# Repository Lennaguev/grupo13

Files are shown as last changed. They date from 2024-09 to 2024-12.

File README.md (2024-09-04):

# Fundamentos de biodiseño

| Integrantes: | Descripción: | Rol: |
| ----- | :---- | :---- |
| **ABIGAIL KARINA ALCAZAR VARGAS  ** |  Estudiante de 4to ciclo de ingeniería biomédica interesada en ingeniería de tejidos y en señales e imágenes biomédicas. |  **Diseño 3D** *Como encargada del diseño 3D, crearé modelos tridimensionales detallados y ajustaré el diseño protésico según las necesidades del usuario para asegurar que el producto sea funcional y cómodo*. |
| **PAOLO FABIÁN CARRANZA IZQUIERDO  ** |  Estudiante de Ingeniería Biomédica de 4to ciclo interesado en Ingeniería de tejidos y biomecánica. |  **Encargado de la manufactura digital:** *Como encargado de la manufactura digital desarrollaré estrategias para integrar diversas tecnologías en el diseño y fabricación del producto final. Además supervisaré la implementación de herramientas de impresión 3D y corte láser.*  |
|  **LADY PAOLA ECHEVERRÍA VÁSQUEZ** |  Estudiante de 4to ciclo de la carrera de ingeniería biomédica. Interesada en Ingeniería de biomateriales e ingeniería clínica. |  **Coordinadora y encargada del Git:** *Como coordinadora y responsable del Git, gestionaré el control de versiones y cambios en el repositorio. Coordinaré las actualizaciones del proyecto y ofreceré soporte al equipo en el uso de Git. También me aseguraré de que la documentación e información sea precisa y confiable.* |
| **LENNA ZURIEL GUEVARA GUILLEN  ** |  Estudiante de 4to ciclo de la carrera de ingeniería biomédica. Interesada en Ingeniería de tejidos y en Biomecánica. |  **Encargada de la elaboración del prototipado:** Como encargada de la *elaboración del prototipado, diseñaré y desarrollaré el prototipo utilizando diversas técnicas y herramientas. Además coordinaré el proceso desde la conceptualización hasta la fabricación, asegurando que los prototipos cumplan con los requisitos y estándares del usuario.*  |
| **VIVIANA NINOSKA RIVERA GUILLÉN  ** |  Estudiante de 4to ciclo de ingeniería biomédica interesada en ingeniería de tejidos y Biomecánica. |  **Encargada del diseño electrónico.** *Como encargada del diseño electrónico, desarrollaré esquemas y circuitos electrónicos para el proyecto, asegurando su funcionalidad y eficiencia. Asimismo, coordinaré y supervisaré la integración de los componentes y sistemas electrónicos al prototipo.* |

[image1]: <>

[image2]: <>

[image3]: <>

[image4]: <>

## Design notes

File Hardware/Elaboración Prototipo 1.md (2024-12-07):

# Elaboración de 1er Prototipo

1. **Diagrama de 4 Módulos HX711 (Diseño Esquemático)**
2. **Soldadura de Cableado a Galgas Extensiométricas:**
   * *Cableado Directo a Galgas*
   * *Soldadura de Terminales a Cables más gruesos y largos*
   * *Soldadura a Terminales Jumper para correcto enganche a Protoboard*
   * *Colocación de Termocompresores en puntos de soldadura*
3. **Inserto de las resistencias y los Terminales finales del cabledo de las galgas (2:2) para establecer 4 Puentes Wheatstone en el Protoboard**
4. **Soldadura de Pines a los módulos HX711**
5. **Encaje de Cables entre los Puentes y las ntradas de módulos HX711**
6. **Conexión de los módulos HX711 a un microcontrolador ESP32**
7. **Carga del código al ESP32 medinte el programa Arduino IDE (con sus respectivas extensiones)**
8. **Establecimiento de un sistema de carga para el ESP32**
    * *Soldadura de pines a un TP4056*
    * *Soldadura de cables con terminal Jumper a un interruptor*
    * *Conexión de caableado Batería Lipo -> TP4056 -> Interruptor -> ESP32*
9. **Lijado de Impresión 3D en PLA para acoplar los componentes electrónicos en sus respectivos espacios**
10. **Testeo de funcionamiento mediante deformaciones controladas de las galgas (sensores resistivos)**

*PDTA.: Mínimo Porcentaje de Éxito en 1er Cableado de Galgas*

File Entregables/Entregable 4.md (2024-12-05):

###     **1.- Caja Negra**


#### **Entradas:**

1. **Fuente de energía:** Mantiene activos los sensores, el sistema de procesamiento de señales, y la comunicación con dispositivos externos para el almacenamiento o transmisión de datos.  
2. **Presión en el muñón:** Datos obtenidos de los sensores  
3. **Forma y tamaño del muñón:** Influye directamente en la distribución de la presión y la forma en que el socket se ajusta al cuerpo del paciente.

#### **Salidas:**

1. **Datos sobre zonas de máxima presión:** Información precisa sobre las áreas específicas del muñón donde se ejerce la mayor presión, representada en forma de gráficos o valores numéricos.  
2. **Información sobre la distribución de fuerzas en situaciones dinámicas:** Datos que muestran cómo cambian las fuerzas en el muñón durante actividades como caminar, correr o subir escaleras.

### **2.- Esquema de Funciones**

* **Operar:** Operar los sensores alimentando enérgicamente los componentes del proyecto  
* **Captura:** Capturar los datos de la muestra (presión, tensión y cambio volumétrico) mediante los sensores  
* **Almacenar:** Almacenar los datos capturados para que pueda ser utilizado posteriormente por el médico  
* **Procesar:** Procesar los datos e información obtenida.  
* **Avisar:** Avisar cuando se excedan los rangos de presión y tensión preestablecidos.  
* **Transmitir:** Hacer pasar el cambio de datos almacenados a través del tiempo por el circuito hasta el punto de visualización.

### **3.- Matriz Morfológica**  


### **4.- Tabla de valoración**

|  |  | Conceptos de solución |  |  |
| :---- | :---- | :---- | :---- | :---- |
| **Número** | **criterios técnicos y económicos** | **Opción 1** | **Opción 2** | **Opcion 3** |
| **1** | **Facilidad de uso** | **4** | **1** | **2** |
| **2** | **Seguridad** | **4** | **3** | **3** |
| **3** | **Costo de tecnología** | **4** | **2** | **2** |
| **4** | **Precisión del dispositivo** | **3** | **3** | **4** |
| **5** | **Tamaño** | **4** | **4** | **4** |
| **6** | **Ligereza** | **4** | **3** | **2** |
| **7** | **Nivel de innovación** | **4** | **2** | **3** |
| **Suma total** |  | **27** | **18** | **20** |

### **5.- Conclusión:**

La opción 1 se destaca entre las tres propuestas debido a que obtuvo la mayor puntuación en la tabla de valoración, lo que refleja su superioridad en varios aspectos clave. Su diseño e implementación son intuitivos y amigables para los usuarios, lo que facilita su uso. Además, sobresale en términos de seguridad, haciéndola más confiable y reduciendo los riesgos potenciales para los usuarios. Otro aspecto importante es su alta calificación en cuanto a tamaño y ligereza, lo que la convierte en una opción altamente portátil y cómoda para el uso prolongado, lo cual es fundamental en aplicaciones donde la movilidad es crucial. Aunque la opción 1 no es la más precisa de todas las alternativas presentadas, los datos que proporciona son lo suficientemente confiables para cumplir con los requisitos del proyecto. 

### **6.- Bocetos:**

#### Boceto 1:
###### TÍTULO DE PROPUESTA: CALCETÍN SEMI-FLEXIBLE DE SILICONA PARA MONITOREO DE PUNTOS DE PRESIÓN NOTIFICADO DE MANERA INALÁMBRICA
Bocetos Propuesta 1 FUNBIO

#### Boceto 2:


LISTA DE DESPIECE:
| Pieza | Nombre | Material |
| :---- | :---- | :---- |
| 1 | 16/8 galgas extensiométricas |
| 2 | Batería |
| 3 | Interruptor |
| 4 | 1 Arduino Nano / ESP32 |
| 5 | Resistencias |
| 6 | Protoboard |
| 7 | Recubrimiento general | Silicona |
| 8 | Cajita para Microcontrolador Energizado | PLA |
| 9* | Módulo Bluetooth HC05 |
|10* | Pantalla LCD 4x20 |
|11* | Módulo I2C |
|12* | 4 Módulos HX711 |

(*) -> Por definir si será requerido al final (más parte B)

##### DESCRIPCIÓN DE FUNCIONAMIENTO:

Esta superficie se encarga de medir presión en determinados puntos principales en el muñón, colocando esta al interior del socket. La información que captan sus sensores es enviada vía Bluetooth a una pantalla, la cual puede ser un celular, con lo que se puede ver los puntos que presentan presiones superiores o inferiores a lo normal. El más peligroso será alertado con un mensaje de "Cuidado" o "!!!".



























































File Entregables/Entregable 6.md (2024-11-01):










https://cad.onshape.com/documents/64f8fe0cf73936eec21aee19/w/a115c0a505cd3cc3481bd7ef/e/b61a0160956c2c94d8190df8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

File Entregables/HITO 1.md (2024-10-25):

Captura de pantalla 2024-10-24 222601





















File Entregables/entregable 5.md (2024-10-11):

**1.- Esquema Electrónico de la solución planteada**  
****

**2.- Modelado 3D**  


![][![image](https://github.com/user-attachments/assets/08fa5246-66a7-4291-986a-df6649042290)


[https://skfb.ly/prHDR](https://skfb.ly/prHDR) 



[https://skfb.ly/prHEy](https://skfb.ly/prHEy) 



[https://skfb.ly/prHEH](https://skfb.ly/prHEH) 



[https://skfb.ly/prHEL](https://skfb.ly/prHEL)



[https://skfb.ly/prHEO](https://skfb.ly/prHEO)  



[https://skfb.ly/prHF8](https://skfb.ly/prHF8)  



[https://skfb.ly/prHF9](https://skfb.ly/prHF9)



[https://skfb.ly/prHFx](https://skfb.ly/prHFx)  



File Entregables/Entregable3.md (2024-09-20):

**Problemática**

- **Contexto:**  
  El proceso de amputación de miembros inferiores es un procedimiento quirúrgico irreversible que se lleva a cabo por causas traumáticas (accidentes o lesiones) o no traumáticas (enfermedades como la diabetes o problemas vasculares) \[1\]. A nivel global, las amputaciones de miembros inferiores representan el 65% del total de personas amputadas, de las cuales el 44.6% son de nivel A.K. (por encima de la rodilla) \[2\]. Asimismo se sabe que en países desarrollados, la principal causa de estas amputaciones son las complicaciones asociadas a enfermedades preexistentes, mientras que en países en vía de desarrollo, los accidentes y traumas son los principales factores \[3\]. En el ámbito de la ingeniería biomédica, esta situación adquiere gran relevancia debido a la necesidad de desarrollar soluciones que ayuden a los pacientes a enfrentar desafíos físicos, psicológicos y sociales y a recuperar su movilidad y calidad de vida. Las prótesis avanzadas, el tratamiento postoperatorio, y la rehabilitación integral son áreas clave en las que la ingeniería biomédica desempeña un papel fundamental para mitigar los efectos de la amputación y facilitar la reintegración de los pacientes a su vida cotidiana.  
- **Definición del problema:**  
  El problema específico que se aborda es la ***falta de una adecuada adaptabilidad de las prótesis al muñón en pacientes con amputación a nivel AK F3,*** lo que dificulta la marcha y reduce la eficacia del proceso de rehabilitación. Este problema surge debido a varios factores, como la forma irregular del muñón, la presión inadecuada en áreas sensibles, y el uso de materiales o tecnologías que no permiten un ajuste preciso. La consecuencia directa es una marcha inestable y dolorosa, que limita la movilidad y la independencia del paciente, afectando su bienestar físico y emocional.   
- **Impacto:**   
  El impacto de la falta de adaptabilidad adecuada de las prótesis no solo afecta la movilidad y calidad de vida de los pacientes, sino que también genera mayores costos médicos para el sistema de salud. Una prótesis mal adaptada puede ocasionar diversas complicaciones físicas, tales como **heridas en el muñón,**  **neuromas** y **necrosis** \[2,4\], las cuales suelen requerir tratamientos adicionales, hospitalizaciones prolongadas y, en algunos casos, revisiones quirúrgicas o cambios de prótesis. Estos problemas incrementan la necesidad de atención médica continua, lo que genera una presión significativa sobre los recursos y los costos del sistema de salud. Además, los pacientes con prótesis mal ajustadas pueden sufrir dolor crónico, mayor riesgo de infecciones, y dificultades para realizar actividades cotidianas, lo que afecta gravemente su calidad de vida y su capacidad para lograr una rehabilitación exitosa. A nivel económico, los costos adicionales derivados de los procedimientos médicos repetidos y la necesidad de prótesis nuevas o reajustadas representan un desafío para los sistemas de salud, que deben invertir más recursos en la atención de estos pacientes. Estos costos se ven reflejados en un uso ineficiente de los servicios de rehabilitación y un aumento en las tasas de reingreso hospitalario. Por lo tanto, el desarrollo de prótesis mejor adaptadas y personalizadas no solo mejoraría la calidad de vida de los pacientes, sino que también reduciría los costos asociados a complicaciones postoperatorias y el uso prolongado de los servicios médicos, beneficiando tanto a los pacientes como a los sistemas de salud en general.

**Propuesta de solución:** 

- **Descripción de la solución:**   
- Se plantea el desarrollo de un revestimiento de silicona semi-flexible, en el cual se integrarán galgas extensiométricas con la capacidad de medir de manera precisa los puntos de mayor presión, compresión y tensión ejercidos sobre el muñón. Este revestimiento se colocará antes del encaje protésico, permitiendo obtener un mapa detallado de las fuerzas que actúan sobre las distintas áreas del muñón durante su interacción con el socket.  
- El objetivo principal de esta tecnología es facilitar la identificación de las zonas que requieren ajustes en el diseño del socket, permitiendo reducir significativamente el tiempo de personalización del mismo. Al obtener información precisa y en tiempo real sobre las zonas de alta presión o tensión, será posible adaptar el socket de manera más rápida y efectiva, mejorando la comodidad y reduciendo las posibilidades de lesiones o irritación para el paciente. De esta forma, se optimiza el proceso de diseño del encaje protésico, garantizando que se satisfagan las necesidades individuales del usuario.

- **Características:**  
- Mide la presión ejercida sobre el muñón mientras el usuario realiza sus actividades diarias, lo que permitirá identificar las posiciones y movimientos que generan más variación de presión.  
- A través de los datos recopilados, se podrán identificar las zonas que están sometidas a una presión excesiva, ayudando así a que la personalización del encaje sea precisa.  
    
- **Beneficios:**   
- Al ser solo un revestimiento no está limitado a un tipo de socket en específico, sino que puede ser usado debajo de cualquiera de estos.  
- Además de mejorar la elección del socket adecuado para el usuario en la etapa inicial, en etapas posteriores se puede utilizar para identificar variaciones en el volumen del muñón y así realizar los ajustes necesarios en el socket del usuario.  
    
- **Viabilidad Técnica:**   
    
  **Materiales:**  
- **Silicona:** El material del revestimiento debe ser cómodo, biocompatible y duradero. La silicona es ideal por su elasticidad, capacidad de adaptación al muñón y resistencia al desgaste. Además, debe ser lo suficientemente fina para no interferir con la precisión de los sensores.  
- **Galgas extensiométricas**: Son sensores de alta precisión que detectan cambios en la tensión mecánica del material. Las galgas deben ser miniaturizadas y lo suficientemente sensibles para captar los pequeños cambios que ocurran en las distintas zonas del muñón.  
  **Componentes electrónicos:**  
- **Microcontroladores**: Dispositivos como Arduino o Raspberry Pi para procesar las señales provenientes de las galgas extensiométricas y convertirlas en datos de utilidad.    
- **Baterías o fuentes de energía autónomas**: baterías pequeñas, recargables y de larga duración para no interferir con la comodidad del usuario.  
  **Software de análisis:**  
- **Programa de procesamiento de datos**: El desarrollo de un software especializado es crucial para analizar los datos obtenidos por las galgas. Este software debe generar mapas de presión y tensión

  **Conocimientos necesarios:**

- ### Diseño e integración de galgas extensiométricas en materiales como la silicona, así como la creación de circuitos y sistemas electrónicos capaces de manejar múltiples entradas de sensores. Se controlará el flujo de cargas mediante resistores agrupados según lo que necesite cada parte de circuito.

- Conocimiento de la biomecánica del muñón, para saber dónde colocar los sensores y cómo interpretar las deformaciones detectadas. Es importante comprender cómo el muñón interactúa con el socket y cómo varían las fuerzas en diferentes actividades.  
- Programación y diseño de interfaces para desarrollar el software que procesará los datos. Este punto se desarrollará teniendo en cuenta los conocimientos previos adquiridos en la carrera, como en el curso de Fundamentos de Programación y Diseño Industrial.

  **Coherencia**

- **Contexto del Proyecto:**  
  La propuesta solución elegida en este caso es el revestimiento de silicona con galgas extensiométricas que midan los puntos de presión, compresión y tensión en el muñón. Consideramos que esta propuesta es necesaria en este caso debido a que el principal problema que identificamos entre amputados que logramos entrevistar; Fue que comúnmente cuando se les daba la primera prótesis era muy común que esta no les quedará del todo bien por aumento de peso, diferente ajuste, entre otras. Lo cual conllevaba a un rediseño del socket.  
  Lo que busca nuestra solución es hacer el proceso de la prueba del socket menos tedioso y  más cómodo para el paciente; Ya que este revestimiento formado por galgas extensiométricas que iría antes de poner el socket mediría como se deforma el muñón en el tiempo, en la primera etapa de creación del socket, dando estos resultados al médico para que pueda reducir el tiempo de prueba del socket con los resultados obtenidos.  
  La manera en la que se integra al entorno general de ingeniería biomédica es porque se usarán biomateriales como la silicona el cual es un polímero que se usa en distintos instrumentos biomédicos gracias a su característica elasticidad. Por otro lado, para medir las presiones y tensiones se utilizaran biosensores y las galgas también medirán el volumen de todo el muñón. El campo de ingeniería biomédica genera este tipo de soluciones que mejoran el proceso ya existente en este caso de prueba de socket con una herramienta biomédica hecha a partir de biomateriales que simplifique y agilice este proceso.  
    
- **Objetivos del Proyecto:**   
  El *objetivo general* de la propuesta de solución es simplificar el proceso de prueba del socket para que se realicen las menores pruebas posibles y el paciente pueda usar su socket y que este se ajuste bien.  
  Mientras que los *objetivos específicos* son que mientras este revestimiento conformado por galgas mida el tamaño del muñón también pueda dar datos de donde se produce los puntos de presiones y tensiones del muñón. Para que así se identifique donde deberían producirse y donde no. De esta forma estos datos también serán de conocimiento del médico que lo tendrá en consideración durante el desarrollo del socket y para la prevención de posibles heridas por exceso de presión en puntos sensibles.  
     
- **Justificación del Prototipo:**   
  Consideramos que nuestra propuesta de solución es innovadora frente a otras del mercado debido a que este es un revestimiento hecho de silicona que es un material que, además de cómodo, su principal función es que evita el contacto directo del muñón con el socket. A pesar de que ya existen revestimientos para que el muñón no tenga contacto directo con el socket, la gran diferencia radica en que nuestra solución contiene galgas que miden los puntos de presión claves dentro del muñón a lo largo del tiempo para conocer cómo se presenta su sensibilidad. Además, estos sensores de presión distribuidos en el revestimiento ayuda para notificar al médico si se está haciendo presión en algún lugar específico sensible que podría generarle heridas al pacientes, lo que prevendría lo que, en casos normales, implicaría la suspensión del uso de la prótesis temporalmente.  
    
- **Alineación con el Problema:**   
  La problemática específica es la falta de adaptabilidad de la prótesis al muñón y cómo esto puede generar complicaciones. Parte de estas complicaciones son heridas que se pueden ocasionar en el muñón, las cuales generarán costos adicionales al paciente para tratar este problema, y no solo al paciente, sino también al sistema de salud. El prototipo aborda eficazmente la problemática, ya que se caracteriza por medir con precisión la presión que genera el el muñón sobre el socket y en qué zonas se dan presiones excesivas que pueden causar complicaciones. Con los datos proporcionados de las mediciones, se podrán realizar ajustes personalizados rápidamente lo  que facilitará la adaptabilidad de la prótesis al muñón.  

- **Resumen:**  
  El problema identificado radica en la falta de adaptabilidad de las prótesis al muñón en pacientes con amputación por encima de la rodilla (nivel AK F3), lo que afecta negativamente su movilidad y proceso de rehabilitación. La forma irregular del muñón y la distribución desigual de presión y tensión en las áreas sensibles del muñón contribuyen a una marcha inestable y dolorosa, limitando la independencia del paciente.   
  La solución propuesta es desarrollar un revestimiento de un biomaterial semi-flexible que contenga galgas extensiométricas. Estas galgas medirán la presión, tensión y cambio volumétrico del muñón de forma instantánea, lo cual nos proporcionará información precisa y detallada de las diversas presiones que actúan en distintas partes específicas del muñón durante el uso de la prótesis. Esto permitirá ajustar de manera minuciosa y rápida el socket protésico, mejorando la comodidad y reduciendo las posibilidades de lesiones o irritación en el paciente.  
- **Resultados esperados:**   
  Al desarrollar esta solución, se espera obtener:  
- Un proceso más eficiente y preciso de personalización del socket protésico el cual  optimizará el tiempo de rehabilitación de los pacientes.  
- Una reducción en el número de pruebas de ajuste de socket, lo que resultaría en menos incomodidad para el paciente.  
- Mejora en la calidad de vida del paciente, al evitar complicaciones como heridas o necrosis debido a una mala adaptación.  
  Para testear conceptualmente el prototipo, se podría realizar una simulación en la que se evalúe cómo el revestimiento con galgas responde a diferentes niveles de presión y tensión. Estos resultados se utilizarían para ajustar el diseño del socket con la finalidad de que se reduzca significativamente el tiempo de personalización antes de su fabricación final.  
- **Siguientes pasos**  
- Desarrollar un prototipo inicial del revestimiento con los materiales y componentes electrónicos propuestos.  
- Realizar pruebas en condiciones controladas para validar la precisión de las galgas extensiométricas en la medición de la presión y tensión.  
- Reformular el diseño y realizar ajustes basados en los resultados de las pruebas.  
- Desarrollar el software necesario para procesar los datos obtenidos y generar estadísticas de datos útiles para los médicos.

**Referencias Bibliográficas:**  
\[1\]  UC San Diego Health, "Cardiovascular Tests and Procedures," MyHealth, \[En línea\]. Disponible en: [https://myhealth.ucsd.edu/Spanish/TestsProcedures/Cardiovascular/92,P09333](https://myhealth.ucsd.edu/Spanish/TestsProcedures/Cardiovascular/92,P09333).  \[Accedido: 27-Ago-2024\].   
\[2\] Amputee Coalition, "Above Knee Amputation," Amputee Coalition, Aug. 2024\. \[En línea\]. Disponible en: [https://www.amputee-coalition.org/wp-content/uploads/2024/08/Above-Knee-Amputation-English.pdf](https://www.amputee-coalition.org/wp-content/uploads/2024/08/Above-Knee-Amputation-English.pdf).  \[Accedido: 27-Ago-2024\].   
\[3\] T. Kaylor, "INCIDENCE AND COMMON CAUSES OF MAJOR LOWER LIMB AMPUTATION AT A HOSPITAL IN A SUB-DISTRICT OF THE CITY OF CAPE TOWN MUNICIPALITY." Master's thesis, University of the Western Cape, 2024\. \[En línea\]. Disponible en: [https://etd.uwc.ac.za/xmlui/bitstream/handle/11394/10643/kaylor\_chs\_m\_2024.pdf?sequence=1\&isAllowed=y](https://etd.uwc.ac.za/xmlui/bitstream/handle/11394/10643/kaylor_chs_m_2024.pdf?sequence=1&isAllowed=y).  \[Accedido: 27-Ago-2024\].   
\[4\] M. Rodríguez, "Características clínicas y epidemiológicas de los pacientes amputados en el Hospital General de Ciego de Ávila," Revista Médica de Ciencias de la Salud, vol. 8, no. 2, pp. 123-130, 2023\. \[En línea\]. Disponible en: [https://revmediciego.sld.cu/index.php/mediciego/article/view/632/1171](https://revmediciego.sld.cu/index.php/mediciego/article/view/632/1171).  \[Accedido: 27-Aug-2024\].

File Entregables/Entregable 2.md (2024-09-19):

1. **Contexto comercial:**
   
   *1.1 Equipos o dispositivos existentes:*

|  Equipos  |  Resumen  |  Imagen  |
| :---- | :---- | :---- |
|  Rodilla de tipo policéntrico [\[1\]](https://dspace.ups.edu.ec/bitstream/123456789/19995/1/UPS-CT008995.pdf)  |  Está destinada para la adaptación protésica de los pacientes. Hay distintos modelos de rodillas policéntricas pero el sistema en el que se basa su funcionamiento es el de distintos puntos de pivote que permiten un movimiento oscilatorio de la rodilla, mejorando así la marcha del paciente. La innovación que se le hace a estos equipos es el material con el que se fabrican siendo que por tecnologías aditivas el coste y el material utilizado presentan un costo y tiempo de fabricación más bajos del mercado. [\[1\]](https://dspace.ups.edu.ec/bitstream/123456789/19995/1/UPS-CT008995.pdf)  |    |
|  Revestimiento de sellado Skeo [\[2\]](https://www.ottobock.com/de-de/product/6Y110)  |  Este revestimiento está compuesto de silicona, que ofrece una mejor comodidad en el usuario, es sencillo de colocar, además, según la experiencia del usuario, se siente seguro a no perder la prótesis y al no tener una tela exterior no almacena agua. [\[2\]](https://www.ottobock.com/de-de/product/6Y110) Especificaciones del producto: Grado de movilidad (2,3,4); Peso corporal máximo: sin límite; para Nivel de amputación transfemoral.  |    |
|  Almohadillas de presión [\[3\]](https://www.ossur.com/es-mx/protesica/encajes/pressure-pads)  |  Tienen el objetivo de redistribuir los puntos de presión que hay en el muñón que se dan en zonas ósea prominentes. El material es de silicona no comprensible y que pueden mejorar la comodidad de los encajes laminados, termoformados o fabricados directamente. [\[3\]](https://www.ossur.com/es-mx/protesica/encajes/pressure-pads) Especificaciones del producto: Niveles de impacto (Bajo, moderado, alto y extremo); para Nivel de amputación Transfemoral y Transtibial. |    |

   *1.2 Patentes*
|  Patente de invención  |  Ficha Técnica  |  Resumen  |  Imagen  |
| :---- | :---- | :---- | :---- |
|  Electrodo Flexible para detectar cambios en la Temperatura, Humedad y Concentración de iones de Sodio en el sudor [\[4\]](https://patentscope.wipo.int/search/en/detail.jsf?docId=US90328810)  | ***N° de patente:*** US20130197319. ***Procedencia:*** Estados Unidos. ***Inventores:*** Chelsea N Monty; Evan K Wujcik; Nathaniel Jacob Blasdel.  |  La invención describe una plataforma flexible de sensores amperométricos para aplicaciones biomédicas, diseñada para monitorear parámetros fisiológicos como temperatura, humedad y concentración de iones, en fluidos corporales mediante detección y diagnóstico de posibles afecciones médicas como irritación o infecciones. Se menciona su uso en el diagnóstico de fibrosis quística y la monitorización de prótesis en amputados. El sensor incluye capas de nanocompuestos y materiales conductivos como nanotubos de carbono y conductores MWCNT y PPy. Proporciona detección en tiempo real y se destaca por su flexibilidad, lo que mejora el confort y la precisión en su aplicación sobre la piel. [\[4\]](https://patentscope.wipo.int/search/en/detail.jsf?docId=US90328810)  |    |
|  Socket integrado para Prótesis que contiene sensor de resistencia [\[5\]](https://worldwide.espacenet.com/patent/search/family/082401693/publication/KR102416665B1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)  |  ***N° de patente:*** KR102416665B1. ***Procedencia:*** Corea. ***Inventores:*** KIM JOO HYUNG; LEE SUN KON; KWON HYEON JUNG; SHIN KYEONG HO; KIM JOO HYUNG; LEE SUN KON; KWON HYEON JUNG; SHIN KYEONG HO.  |  Esta patente de socket está diseñada con el objetivo de ser más cómodo para el amputado mediante material blando elástico, que está integrado dentro del socket, así no provocará dolores en la persona cuando varíe su volumen como es el caso de un aumento del peso corporal, además consta de un sensor de resistencia que mide el cambio de volumen y que posteriormente de los datos obtenidos se podrán utilizar para tratamientos y rehabilitación del usuario.[\[5\]](https://worldwide.espacenet.com/patent/search/family/082401693/publication/KR102416665B1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)  |    |
|  Dispositivo para monitorear la presión/temperatura para Prótesis [\[6\]](https://worldwide.espacenet.com/patent/search?q=pn%3DMXPA05004653A)  |  ***N° de patente:*** MXPA05004653A. ***Procedencia:*** México. ***Inventores:*** CASPERS CARL A.  |  Este dispositivo consiste en un conjunto de sensores (presión, fuerza, temperatura, humedad y vacío) que permiten detectar nivel fuera de la saludable en la unión entre el miembro residual y el receptáculo como una descolocación por un insuficiencia en la bomba de vacío; por inflamación o pérdida de irrigación sanguínea; o por demasiado humedad debido a sudor. [\[6\]](https://worldwide.espacenet.com/patent/search?q=pn%3DMXPA05004653A)  |    |
|  Sistema de presión de aire diferencial [\[7\]](https://patentimages.storage.googleapis.com/15/db/f9/e8f75be83b4f33/ES2763123T3.pdf)  |  ***N° de patente:*** ES2763123T3. ***Procedencia:*** España. ***Inventores:*** LONG, PHILIP, W.; KUEHNE, ERIC, R.; RAHMAN, BABU, S.; JUE, CLIFFORD, T.; WHALEN, SEAN, TREMAINE; MARECEK, GREGORY, P.; HORST, ROBERT, W.; ABRAHAMI, ADRIAN; CURTISS, CHASE, CAMDEN y ESSOCK-BURNS, EMMA.  |  Un sistema de presión de aire diferencial que tiene capacidades de corrección de la marcha se integra con una prótesis En este ejemplo específico, la integración de un sistema de presión de aire diferencial con capacidades de marcha como se ha descrito anteriormente con capacidades de control por máquina, permite la información o el entrenamiento usando movimiento de memoria muscular. Los sistemas de presión de aire diferencial se puede configurar para dirigir al usuario a opciones de socket y a mejorar su marcha. [\[7\]](https://patentimages.storage.googleapis.com/15/db/f9/e8f75be83b4f33/ES2763123T3.pdf)  |    |

2. **Requerimientos**

    Requisitos Funcionales FUNBIO   Requisitos No Funcionales FUNBIO

4. **Propuesta de Solución**  
   ### “Socket con sensor de presiones que pueda detectar puntos de mayor apoyo, esto para que el paciente pueda mejorar su locomoción y evitar posibles lesiones e incomodidad en el muñón a través de la colocación adecuada de la prótesis o su correcta elaboración de parte de la institución médica en un inicio.”

**7.- Referencias bibliográficas:**

- \[1\] F. V. Pintado Albarracin, G. F. Vintimilla Leon, “Diseño y construcción de una prótesis de rodilla asistida para amputación transfemoral” Sep. 2020. https://dspace.ups.edu.ec/bitstream/123456789/19995/1/UPS-CT008995.pdf 
- \[2\] Ossur “Skeo Sealing Liner” 2024 https://www.ottobock.com/de-de/product/6Y110   
- \[3\] Ossur “Pressure pads” 2024 https://www.ossur.com/es-mx/protesica/encajes/pressure-pads    
- \[4\] Chelsea N Monty, Evan K Wujcik, Nathaniel Jacob Blasdel, “WIPO - Search International and National Patent Collections.” Aug. 01, 2013. https://patentscope.wipo.int/search/en/detail.jsf?docId=US90328810 
- \[5\] KIM JOO HYUNG; LEE SUN KON; et al., “Integrated Socket For Prosthesis Including Resistance Sensor.” Julio, 05, 2022. https://worldwide.espacenet.com/patent/search/family/082401693/publication/KR102416665B1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 
- \[6\] Caspers Carl A, “Pressure/Temperature Monitoring Device For Prosthetics” Septiembre, 20, 2005. https://worldwide.espacenet.com/patent/search?q=pn%3DMXPA05004653A
- \[7\] Long, Philip, W.; Kuehne, Eric, R.; et al., “Cámara de presión y elevador para sistema de presión de aire diferencial con capacidad de recogida de datos médicos” Nov. 06, 2019. https://patentimages.storage.googleapis.com/15/db/f9/e8f75be83b4f33/ES2763123T3.pdf

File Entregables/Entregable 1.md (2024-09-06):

1. **Definiciones de términos clave:**  
* ***Amputación de miembro inferior derecho AK F3:*** Esta amputación implica extirpar la parte superior de la rodilla a la altura del tercio inferior del fémur.  
* ***Diabetes Mellitus :*** Enfermedad crónica que implica niveles altos de glucosa en la sangre.
* ***Accidente automovilístico:*** Consecuencia de una colisión de coche  
* ***Terapia Preprotésica:*** Se prepara a la persona para el manejo de la prótesis provisional o pilón.
* ***Fase Protésica:*** Se aprende a colocarse y retirarse la prótesis, así como la continuación de la rehabilitación tanto física como funcional.
    
2. **Análisis de la temática y/o caso:**  
   *2.1 Contexto mundial:* 

La amputación de miembro inferior es un procedimiento quirúrgico irreversible que consta de la extirpación total o parcial de una extremidad del cuadrante inferior. Estas pueden ser causadas como consecuencia de un accidente o lesión *(Amputación traumática)* o enfermedad *(Amputación no traumática)*.[\[1\]](https://myhealth.ucsd.edu/Spanish/TestsProcedures/Cardiovascular/92,P09333) 
Los niveles de amputación existentes se clasifican de dos formas \[2\]:  
**a.- Clasificación anatómica de Oxford:** 

###### TABLA I: CLASIFICACIÓN ANATÓMICA SEGÚN OXFORD
| MIEMBROS INFERIORES |
| :---: |
| F: Segmento femoral
F1: Tercio superior del fémur
F2: Tercio medio del fémur
F3: Tercio inferior del fémur
T: Segmento tibial
T1: Tercio superior de tibia
T2: Tercio medio de tibia
T3: Tercio inferior de tibia |

**b.- Clasificación topográfica de Schwartz:**

###### TABLA II: CLASIFICACIÓN SEGÚN SCHWARTZ
| MIEMBROS INFERIORES |
| :---: |
| Hemipelvectomía
Desarticulación de cadera
Amputación por encima de la rodilla (A.K.)
Desarticulación de rodilla
Amputación corta bajo rodilla (short B.K.)
Amputación por debajo de la rodilla (B.K.)
Amputación de Syme
Amputaciones parciales del pie|

A nivel internacional, la amputación de miembros inferiores es la más común ya que constituye un 65% del porcentaje total de personas amputadas [\[3\]](https://www.amputee-coalition.org/wp-content/uploads/2024/08/Above-Knee-Amputation-English.pdf). De esta cifra, el 44,6% está compuesta de pacientes que han sido amputadas a nivel por arriba de la rodilla (A.K.). En los países desarrollados la mayor causa de amputaciones son complicaciones de enfermedades preexistentes *(Amputación no traumática)* siendo la diabetes y enfermedades vasculares las mayores originantes, por otro lado, en países subdesarrollados la mayor causa de amputaciones son accidentes o lesiones *(Amputación traumática)* [\[4\]](https://etd.uwc.ac.za/xmlui/bitstream/handle/11394/10643/kaylor_chs_m_2024.pdf?sequence=1&isAllowed=y).  
Una amputación trae consigo consecuencias físicas, funcionales, psicológicas y sociales, es por esto que el tratamiento posterior al procedimiento debe componerse de varias etapas guiadas con la ayuda de distintos especialistas, tales como médicos, fisioterapeutas y psicólogos. El tratamiento post-operatorio consta de 3 etapas [\[5\]](https://www.argentina.gob.ar/inareps/guia-atencion-pacientes-amputados/etapas):

- **Etapa post-quirúrgica:** En esta etapa es primordial la curación de la herida causada por el tratamiento quirúrgico, también se trata de disminuir los dolores y edemas que el paciente pueda sufrir por el mismo. Usualmente se usan vendajes, calcetas, yeso y pomadas. Esta etapa finaliza con la extirpación de los puntos y la cicatrización de la herida. Asimismo en esta etapa se pueden presentar diversas complicaciones con el muñón de las cuales las más frecuentes son las son infecciones en la herida con una presencia del 31.07% en los pacientes, los neuromas con una presencia del 19,64% y la necrosis con una presencia del 32,14%. Por otro lado,  otra de las complicaciones más frecuentes es el famoso síndrome de miembro fantasma el cual tiene una presencia del 80% y es mayormente causado por factores sociales a los que el paciente se encuentra sometido [\[6\]](https://revmediciego.sld.cu/index.php/mediciego/article/view/632/1171) [\[3\]](https://www.amputee-coalition.org/wp-content/uploads/2024/08/Above-Knee-Amputation-English.pdf).  
- **Etapa pre-protésica:** Se desarrolla de 2-3 semanas después de la cirugía y se basa principalmente en la adaptación del paciente a la vida diaria. Asimismo se empieza la confección del “Pilón”, el cual es un molde de yeso el cual es usado para el desarrollo muscular del muñón. Por otro lado, en esta etapa también se empieza a entrenar al paciente para el uso de la prótesis, esto mediante ejercicios de rehabilitación como por ejemplo; Ejercicios de equilibrio, aprender a ponerse la prótesis y prácticas de marcha en distintos terrenos [\[5\]](https://www.argentina.gob.ar/inareps/guia-atencion-pacientes-amputados/etapas).
- **Etapa protésica:** En esta etapa se desarrolla la prescripción de la prótesis considerando las necesidades del paciente. A su misma vez el paciente empieza el proceso de rehabilitación con el uso de la prótesis prescrita mediante técnicas especializadas como el entrenamiento A.V.D [\[5\]](https://www.argentina.gob.ar/inareps/guia-atencion-pacientes-amputados/etapas).

En suma, el objetivo principal del tratamiento al paciente amputado es que este aprenda a usar la prótesis prescrita por su médico, con la finalidad de que este pueda tener una óptima calidad de vida y reemplazar el miembro faltante  El éxito del tratamiento dependerá de distintos factores relacionados tanto al paciente (edad, el estado físico, la motivación que tenga para con su recuperación y el sistema de apoyo que tenga) como al personal de salud y las terapias usadas para su tratamiento [\[7\]](https://www.medigraphic.com/pdfs/revcubmedfisreah/cfr-2016/cfr161d.pdf).

*2.2 Contexto en el Perú:*  
Desde el 2017 al 2022 la región que registró un mayor número de accidentes de tránsitos fue Lima, donde se pudo ver un aproximado de 52% de casos. Durante el 2019 se pudo visualizar una alza de accidentes, presentando así una cantidad de 95 800 a diferencia del del 2020 donde se visualizó un descenso de accidentes debido al contexto histórico por el cual estaba pasando el mundo, donde la cantidad de accidentes presentados fue de 57 396\. Luego del descenso histórico de accidentes automovilísticos que se pudo ver en el año 2020, en el año 2021 se pudo ver una nueva alza de accidentes donde se presentó 74 624 accidentes, de los cuales hubo 49 519 heridos y 3 032 fallecidos.[\[8\]](https://www.defensoria.gob.pe/wp-content/uploads/2023/04/Reporte-Defensorial-de-accidentes-de-tr%C3%A1nsito-N01-Abril-2023.pdf)

###### TABLA III: ACCIDENTES DE TRÁNSITO, HERIDOS Y FALLECIDOS POR SINIESTROS VIALES EN EL PERÚ (2017 – 2022)


Las amputaciones traumáticas del miembro inferior que se dan por accidentes de tránsito  suelen ser a nivel por encima de la rodilla (A.K), en el Perú las amputaciones de este tipo son una de las más frecuentes con una incidencia del 54%; sin embargo, la amputación no traumática es la que se da con mayor frecuencia con una recurrencia del 55% y la causa en su mayoría es la complicación de la diabetes mellitus (42%).[\[9\]](https://www.essalud.gob.pe/ietsi/pdfs/guias/RE_Prescripcion_de_Protesis_Final.pdf)
Aunque un paciente haya sufrido una amputación traumática, el que éste padezca de diabetes será un problema para su tratamiento post-quirúrgico ya que esta enfermedad afecta a la cicatrización debido a que los altos niveles de glucosa en la sangre afectan el flujo sanguíneo ralentizando así el proceso de cicatrización. Lo mencionado influye en la etapa post-quirúrgica del tratamiento del paciente debido a las complicaciones que pueden ocasionarse lo que de la misma forma puede impedir la recuperación de la persona que a su misma vez puede afectar las siguientes etapas de recuperación.
En nuestro país los pacientes amputados solo cuentan con un centro especializado en  rehabilitación integral llamado Instituto Nacional de Rehabilitación (INR), el cual está ubicado en la capital.  En el año 2023 se diagnosticó y trató a  101 personas amputadas de nivel A.K en el Departamento de Amputados, Quemados y Trastornos Posturales (AQTP), los cuales representan el 4.3% de un total de 2347 personas.[\[10\]](https://cdn.www.gob.pe/uploads/document/file/5729586/5088554-rd-009-2024-sa-dg-inr.pdf)



Fig. 1: Indicadores hospitalarios anuales 2023

3. **Cuadro médico**  
   ###### TABLA IV: DESCRIPCIÓN DE CASO REAL CONSIDERADO POR EL GRUPO (INR)

| Prevención  | Diagnóstico  | Tratamiento  | Monitoreo |
| :---- | :---- | :---- | :---- |
| Para caso de antecedente de Diabetes mellitus: Ante posible úlcera isquémica con infección, la gangrena digital y la necrosis tisular (motivos para amputación mayor)[\[12\]](http://scielo.sld.cu/scielo.php?pid=S1682-00372020000300005&script=sci_arttext&tlng=pt), se recomienda tratamiento preventivo [\[13\]](https://scielo.isciii.es/scielo.php?pid=S2529-850X2022000200005&script=sci_arttext):| Amputación de miembro inferior derecho por accidente automovilístico | Radiografía del muñón, exámenes de laboratorio control (hemograma, hemoglobina glicosilada, perfil lipídico.| El 5 de enero del 2022 se procede con la realización de baremo para elaboración de certificado de discapacidad. 
|**\- Cuidado del pie con educación a pacientes:** \* Calzado adecuado \* Higiene adecuada \* Cuidado de heridas y corte de uñas \* Ejercicio físico: Disminuir la presión máxima y aumentar el rango de movimiento del pie y tobillo. **\- Evaluaciones periódicas de riesgos (signos):** \* Revisión de historial clínico: Presencia de enfermedad renal en etapa terminal y de limitaciones físicas \* Análisis del pie en color, temperatura y deformidades \* Presencia de lesiones como hallux valgus, atrofia muscular, deformidad de Charcot, eritema, ampollas, callosidades, fisuras, tinea pedis y uñas encarnadas. \* Pérdida de pulso pedio dorsal o sensación protectora. \* Control glucémico **\- Atención adecuada a úlceras/heridas:** \* Descarga \* Uso de yeso de contacto total \* Técnicas quirúrgicas: Tenotomía del tendón flexor digital, Alargamiento del tendón de Aquiles, tenosuspensión de Jones \* Desbridamiento (infección) \* Revascularización \* Terapia de heridas con presión negativa| | Se prescribe terapia física, ocupacional. Psicología y servicio social. | Luego de 2 meses, le indican uso de prótesis AK modular, socket de resina, con cinturón silesiano, rodilla monocéntrica, y pie SACH. En noviembre, inicia el entrenamiento de marcha al practicar con pilón de yeso, siendo previo a la prótesis definitiva. En ese momento se encontraba en espera de cobertura de seguro para su prótesis. Un año después, acude a control y su prótesis pasa a ser elaborada en biomecánica. Se indica terapia física y ocupacional para alineamiento protésico. Finalmente, 3 meses después se realiza el alta de la prótesis AK modular, socket resina, cinturón silesiano, rodilla con freno de fricción y pie SACH. Se prescribe un bastón canadiense.|

4. **Diagrama de Ishikawa**

   ![image](

   Fig. 2: Diagrama de Ishikawa con Causas relacionado a la problemática de Amputados

6. **Definición del problema**
   
   *“Dificultad en la marcha debido a problemas de adaptabilidad de la prótesis al muñón del paciente amputacion nivel AK F3”*   
     
8. **Estado del arte/ contexto científico**  

   ###### TABLA V: PRODUCTOS EN EL MERCADO PARA AMPUTADOS DEL MIEMBRO INFERIOR

| | |
| :---- | ----- |
| PIE SACH | Prótesis sin articulaciones en forma de pie, diseñada para brindar soporte .[\[13\]](https://revistas.uis.edu.co/index.php/revistauisingenierias/article/view/14789) |
| **ORION3** | Prótesis transfemoral que permite a los usuarios replicar el movimiento natural de sus extremidades [\[13\]](https://revistas.uis.edu.co/index.php/revistauisingenierias/article/view/14789) |
| **PLIE** | Prótesis con microprocesador, capaz de soportar hasta 125 Kg.[\[13\]](https://revistas.uis.edu.co/index.php/revistauisingenierias/article/view/14789) |
| **GENIUM** | Prótesis basada en microprocesador cuya batería dura más de 2 días. [\[13\]](https://revistas.uis.edu.co/index.php/revistauisingenierias/article/view/14789) |
| **RHEO KNEE** | Sistema controlado por microprocesador, analiza y se adapta a tus movimientos para brindar más estabilidad a la marcha [\[13\]](https://revistas.uis.edu.co/index.php/revistauisingenierias/article/view/14789) |
| **POWER KNEE** | Prótesis transfemoral capaz de soportar hasta 165 Kg y que promete reducir el tiempo de adaptación de los pacientes.[\[13\]](https://revistas.uis.edu.co/index.php/revistauisingenierias/article/view/14789) |

- También se ha encontrado en un artículo de investigación un sistema de control de prótesis transfemoral basado en redes neuronales. En este se consideraron factores como altura peso y edad del usuario. Además, se utilizó una metodología mecatrónica basada en el modelo V (de requerimientos a producto), con pruebas de predicción de movimientos de flexión y extensión de la pierna en base a la adquisición de datos musculares con sensores específicos como un acelerómetro y sensores MyoWare AT-04-001 con electrodos colocados en bíceps y cuádriceps femorales. Estos alimentan a una red neuronal formada de una capa de 3 entradas con 12 neuronas en la capa oculta y una neurona en la capa de salida que corresponde a la posición final y terminó siendo comparada con datos reales. Este producto terminó con un error del 20% a pesar de presentar coincidencias en el ángulo de movimiento [\[14\]](https://revistas.utadeo.edu.co/index.php/mutis/article/view/diseno-sistema-control-protesis-transfemoral).

Fig. 3: Simulación de flexión y extensión de Prótesis Transfemoral basado en Redes Neuronales



Fig. 4: Integración de subsistemas mecánico y control de Prótesis Transfemoral basado en Redes Neuronales

* **Materiales usados para el proceso de fabricación de prótesis con impresora 3D**  
  Manufactura aditiva: Es el proceso por el cual a través de un programa se puede personalizar un prototipo para luego mandarlo a imprimir a una impresora 3D.

###### TABLA VI:MATERIALES USADOS EN MANUFACTURA ADITIVA (IMPRESIÓN 3D)

| Material | Descripción |
| :---- | :---- |
| Acido Polilactico (PLA) | Buena resistencia a la tracción e ideal para modelos y prototipos que mejoran la calidad de la superficie. requieren detalles estéticos y ser respetuosos con el medio ambiente. [\[17\]](https://digital.csic.es/bitstream/10261/203003/1/777537.pdf)|
| Poliuretano Termoplástico (TPU) | Excelente resistencia al desgarro Flexibilidad excepcional (es decir y al desgaste, alto impacto, alargamiento a la rotura) y resistencia fuerza y dureza a la corrosión para muchos productos químicos y aceites industriales comunes. Material altamente versátil con propiedades de caucho y plástico para una variedad de aplicaciones industriales. [\[16\]](https://digital.csic.es/bitstream/10261/203003/1/777537.pdf)|

Los beneficios de la tecnología aditiva de la impresión 3d  es que mejora notablemente el tiempo de fabricación puesto a que con solo el diseño digital ya se puede empezar a crear la impresión. Además esta innovadora tecnología aplicada al campo de las prótesis usa materiales más amigables con el medio ambiente y que también presentan un menor coste de producción (como se muestra en la tabla). [\[17\]](https://upcommons.upc.edu/handle/2117/173993)


Fig. 5: Coste de Producción en Fabricación de Prótesis [\[17\]](https://upcommons.upc.edu/handle/2117/173993)

###### TABLA VII: MATERIALES TERMOPLÁSTICOS COMÚNMENTE USADOS PARA LA FABRICACIÓN DE SOCKETS
| Materiales Termoplástico | Descripción |
| :---- | :---- |
| Polipropileno (PP) | El polipropileno es el plástico más ligero  utilizado  en  prótesis,  se  caracteriza  por  su  alta resistencia,  a la tracción, rigidez y  dureza.  Entre  sus  limitantes  se resalta su sensibilidad a la deformación y deterioro por calor [\[18\]](https://revistas.unal.edu.co/index.php/revfacmed/article/view/64470/71001)|
| Polietileno (PE) | Se caracteriza por su flexibilidad y también por ser liviano esto ayuda a la fabricación de dispositivos que requieren flexibilidad para usuarios con poco recubrimiento de muñón. [\[18\]](https://revistas.unal.edu.co/index.php/revfacmed/article/view/64470/71001) |

Los materiales termoplásticos son los que son comúnmente usados para la elaboracion de protesis por las buenas propiedades ya mencionados sin embargo presenta algunas desventajas como su sensibilidad a las altas temperaturas.Cabe recalcar que el tiempo de vida útil es corto por lo que no es un material de uso ecoamigable. Sin embargo siguen siendo una opción viable para la elaboración de prótesis.

**7.- Referencias bibliográficas:**

\[1\] UC San Diego Health, "Cardiovascular Tests and Procedures," MyHealth, [En línea]. Disponible en: https://myhealth.ucsd.edu/Spanish/TestsProcedures/Cardiovascular/92,P09333. [Accedido: 27-Ago-2024].  
\[2\] "A Manual for Above-Knee (Trans-Femoral) Amputees"; Rehabilitation Press, Topping, 1996\.  
\[3\] Amputee Coalition, "Above Knee Amputation," Amputee Coalition, Aug. 2024. [En línea]. Disponible en: https://www.amputee-coalition.org/wp-content/uploads/2024/08/Above-Knee-Amputation-English.pdf. [Accedido: 27-Ago-2024].   
\[4\] T. Kaylor, "INCIDENCE AND COMMON CAUSES OF MAJOR LOWER LIMB AMPUTATION AT A HOSPITAL IN A SUB-DISTRICT OF THE CITY OF CAPE TOWN MUNICIPALITY." Master's thesis, University of the Western Cape, 2024. [En línea]. Disponible en: https://etd.uwc.ac.za/xmlui/bitstream/handle/11394/10643/kaylor_chs_m_2024.pdf?sequence=1&isAllowed=y. [Accedido: 27-Ago-2024]. 
\[5\]  Ministerio de Salud de Argentina, "Guía de Atención a Pacientes Amputados: Etapas," Argentina.gob.ar, [En línea]. Disponible en: https://www.argentina.gob.ar/inareps/guia-atencion-pacientes-amputados/etapas. [Accedido: 27-Ago-2024].  
\[6\]  M. Rodríguez, "Características clínicas y epidemiológicas de los pacientes amputados en el Hospital General de Ciego de Ávila," Revista Médica de Ciencias de la Salud, vol. 8, no. 2, pp. 123-130, 2023. [En línea]. Disponible en: https://revmediciego.sld.cu/index.php/mediciego/article/view/632/1171. [Accedido: 27-Aug-2024].  
\[7\] Y. Govantes Bacallao, C. Julio Alba Gelabert, y A. Arias Cantalapiedra, "Protocolo de actuación en la rehabilitación de pacientes amputados de miembro inferior," Revista Cubana de Medicina Física y Rehabilitación, vol. 8, no. 1, pp. 33-43, 2016. [En línea]. Disponible en: https://www.medigraphic.com/pdfs/revcubmedfisreah/cfr-2016/cfr161d.pdf. [Accedido: 27-Aug-2024].
\[8\] Defensoría del Pueblo, "Reporte Defensorial de Accidentes de Tránsito N° 01 - Abril 2023," Defensoría del Pueblo, Apr. 2023. [En línea]. Disponible en: https://www.defensoria.gob.pe/wp-content/uploads/2023/04/Reporte-Defensorial-de-accidentes-de-tr%C3%A1nsito-N01-Abril-2023.pdf. [Accedido: 27-Aug-2024].
\[9\] IETSI, "Reporte de Evidencias N°4. Recomendaciones para la prescripción de prótesis de miembro inferior," Instituto de Evaluación de Tecnologías en Salud e Investigación (IETSI), EsSalud, mayo 2018. [En línea]. Disponible en: https://www.essalud.gob.pe/ietsi/pdfs/guias/RE_Prescripcion_de_Protesis_Final.pdf. [Accedido: 27-Aug-2024]. 
\[10\] K. P. Amaya Solís, L. M. Farro Uceda, y R. Lazarte Hesse, "Evolución de la calidad de vida del amputado de miembro inferior atendido en el Instituto Nacional de Rehabilitación <<Dra. Adriana Rebaza Flores>> AMISTAD PERÚ-JAPÓN," Instituto Nacional de Rehabilitación, 2024. [En línea]. Disponible en: https://cdn.www.gob.pe/uploads/document/file/5729586/5088554-rd-009-2024-sa-dg-inr.pdf. [Accedido: 27-Aug-2024].  
\[11\]  O. Escalante Padrón, A. Hernández Varela, J. L. Valdés Nápoles, y R. J. Álvarez Hidalgo, "Factores pronósticos de amputación mayor en pacientes con pie diabético sometidos a cirugía," Revista Cubana de Medicina Física y Rehabilitación, vol. 19, no. 3, pp. 123-130, 2020. [En línea]. Disponible en: http://scielo.sld.cu/scielo.php?pid=S1682-00372020000300005&script=sci_arttext&tlng=pt. [Accedido: 27-Aug-2024].   
\[12\]  E. Talaya-Navarro, L. Tarraga-Marcos, F. Madrona-Marcos, J. M. Romero-de Avila, y P. J. Tárraga-López, "Prevención de amputaciones relacionadas con el pie diabético," Revista Española de Rehabilitación y Medicina Física, vol. 38, no. 2, pp. 123-135, 2022. [En línea]. Disponible en: https://scielo.isciii.es/scielo.php?pid=S2529-850X2022000200005&script=sci_arttext. [Accedido: 27-Aug-2024].  
\[13\] J. F. Maldonado-Moreno, J. S. Martínez-Castañeda, Y. D. Beltrán-Malaver, I. C. Riveros-Pineda, y G. D. Tovar-Hernández, "Metodología de producción de prótesis de miembro inferior: una revisión exhaustiva," Revista UIS Ingenierías, vol. 21, no. 1, pp. 45-58, 2024. [En línea]. Disponible en: https://revistas.uis.edu.co/index.php/revistauisingenierias/article/view/14789. [Accedido: 27-Aug-2024].    
\[14\] S. Vergara, G. Mosquera, V. Bonilla, M. Sánchez, y C. Rueda, "Diseño de un sistema de control de prótesis transfemoral basado en redes neuronales," Mutis, vol. 16, no. 2, pp. 55-68, 2024. [En línea]. Disponible en: https://revistas.utadeo.edu.co/index.php/mutis/article/view/diseno-sistema-control-protesis-transfemoral. [Accedido: 27-Aug-2024].   
\[15\] L. Serrano-Cinchilla, L. Bustamante-Góez, y J. A. Villarraga-Ossa, "Influencia de la densidad y de los parámetros de relleno en las propiedades mecánicas compresivas de probetas fabricadas en manufactura aditiva de PLA," Revista UIS Ingenierías, vol. 21, no. 2, pp. 75-88, 2022. [En línea]. Disponible en: https://doi.org/10.18273/revuin.v21n2-2022009. [Accedido: 27-Aug-2024].
\[16\] M. León, Á. Marcos-Fernández, y J. Rodríguez-Hernández, "Impresión 3D con materiales elástoméricos," Instituto de Ciencia y Tecnología de Polímeros (ICTP-CSIC), Madrid, España, 2020. [En línea]. Disponible en: https://digital.csic.es/bitstream/10261/203003/1/777537.pdf. [Accedido: 27-Aug-2024]. 
\[17\] G. Gómez Blázquez, "Proyecto de diseño de una prótesis a partir de fabricación aditiva (impresión 3D)," Projecte Final de Màster Oficial, Universitat Politècnica de Catalunya, 16-Jun-2019. [En línea]. Disponible en: https://upcommons.upc.edu/handle/2117/173993. [Accedido: 27-Aug-2024].
\[18\] C. Quintero-Quiroz y V. Zasúlich Pérez, "Materials for lower limb prosthetic and orthotic interfaces and sockets: Evolution and associated skin problems," Revista Facultad de Medicina, vol. 68, no. 2, pp. 123-134, 2019. [En línea]. Disponible en: https://revistas.unal.edu.co/index.php/revfacmed/article/view/64470/71001. [Accedido: 27-Aug-2024].

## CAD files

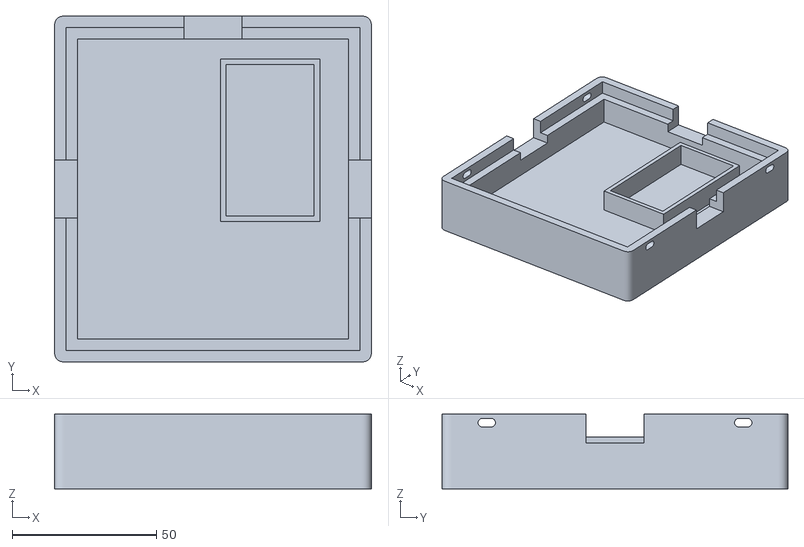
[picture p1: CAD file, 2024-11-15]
Hardware/caja tapa.stl
110.0 x 120.0 x 26.0

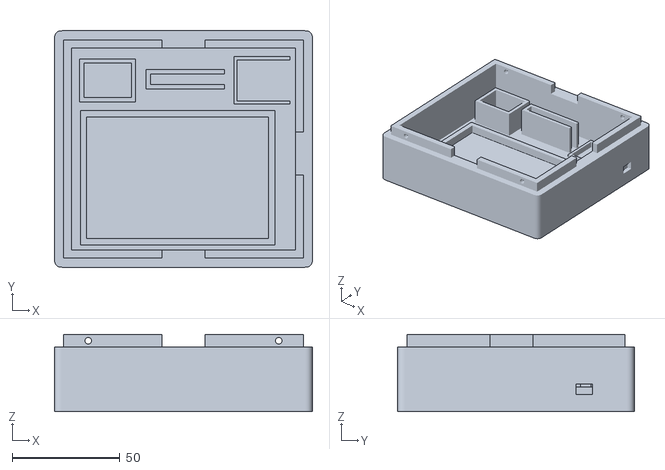
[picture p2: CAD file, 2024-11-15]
Hardware/caja base.stl
120.0 x 110.0 x 36.0

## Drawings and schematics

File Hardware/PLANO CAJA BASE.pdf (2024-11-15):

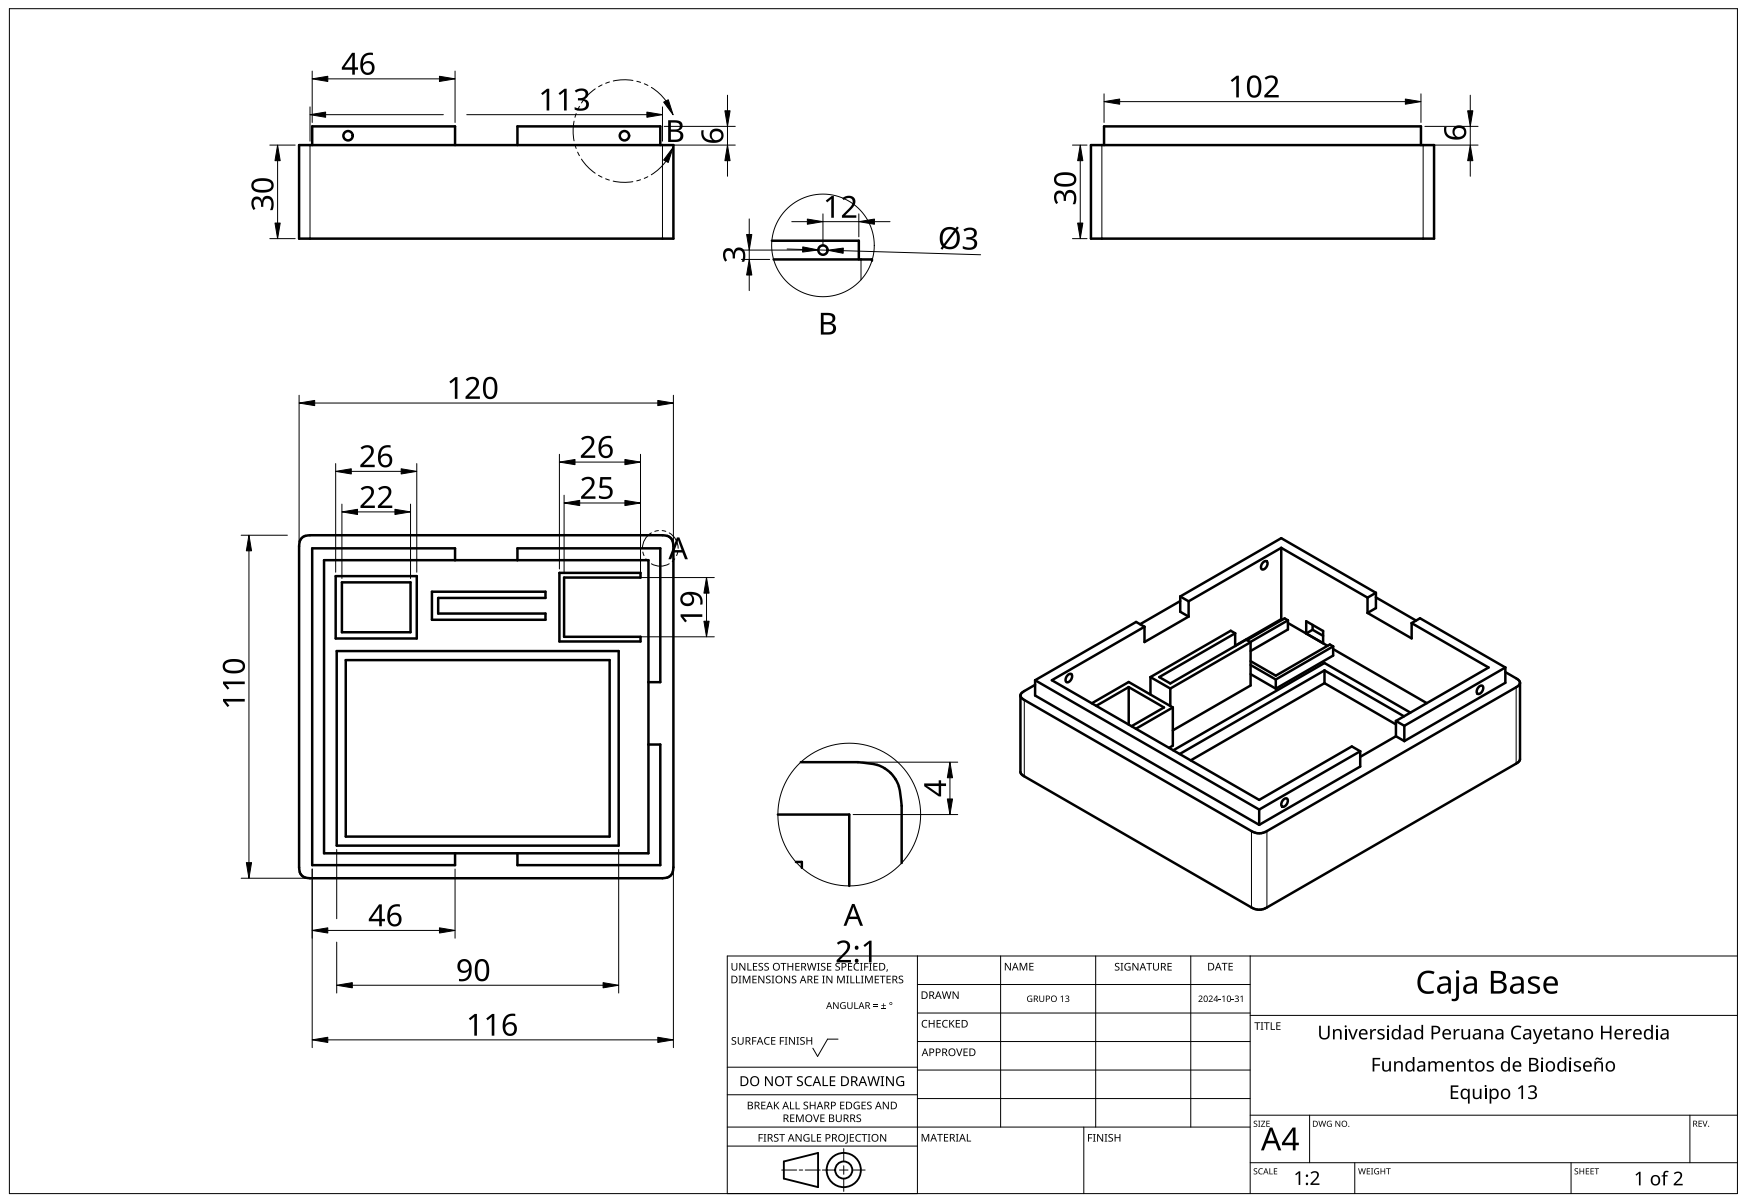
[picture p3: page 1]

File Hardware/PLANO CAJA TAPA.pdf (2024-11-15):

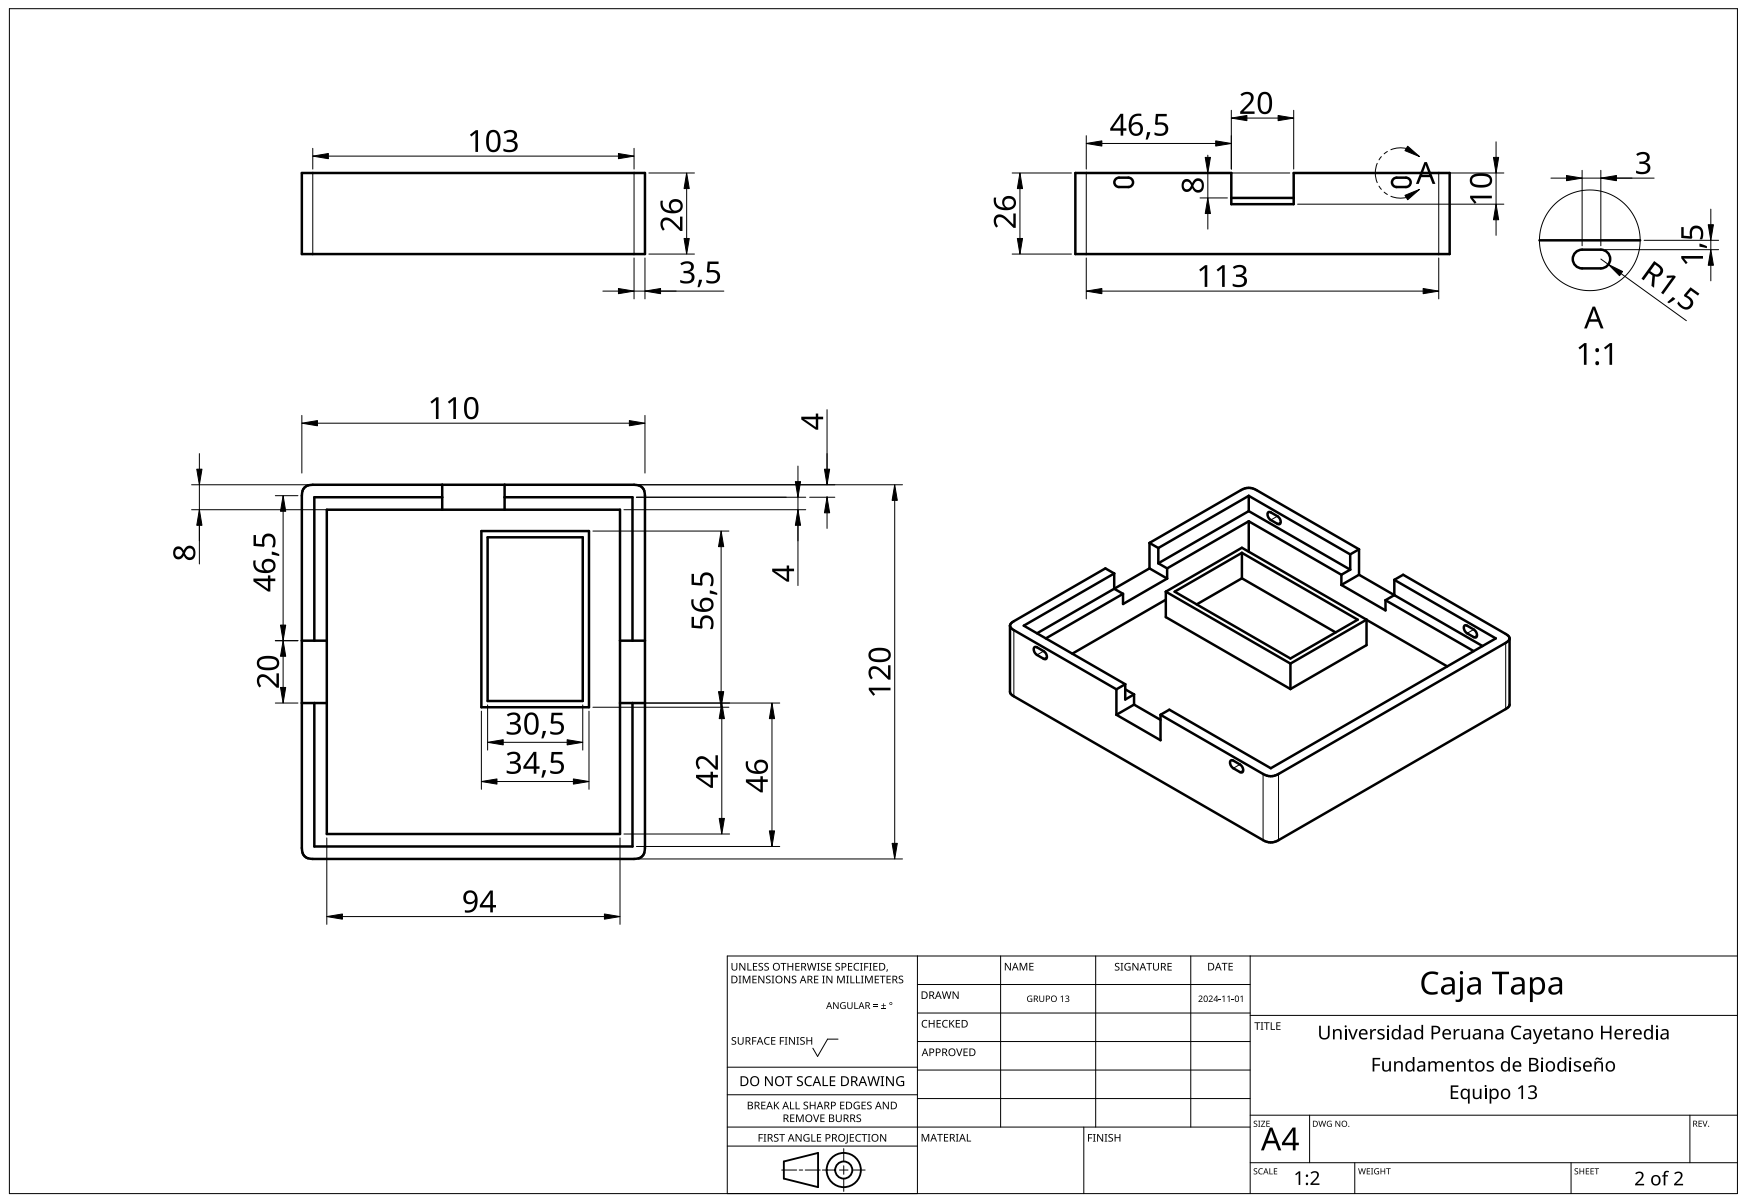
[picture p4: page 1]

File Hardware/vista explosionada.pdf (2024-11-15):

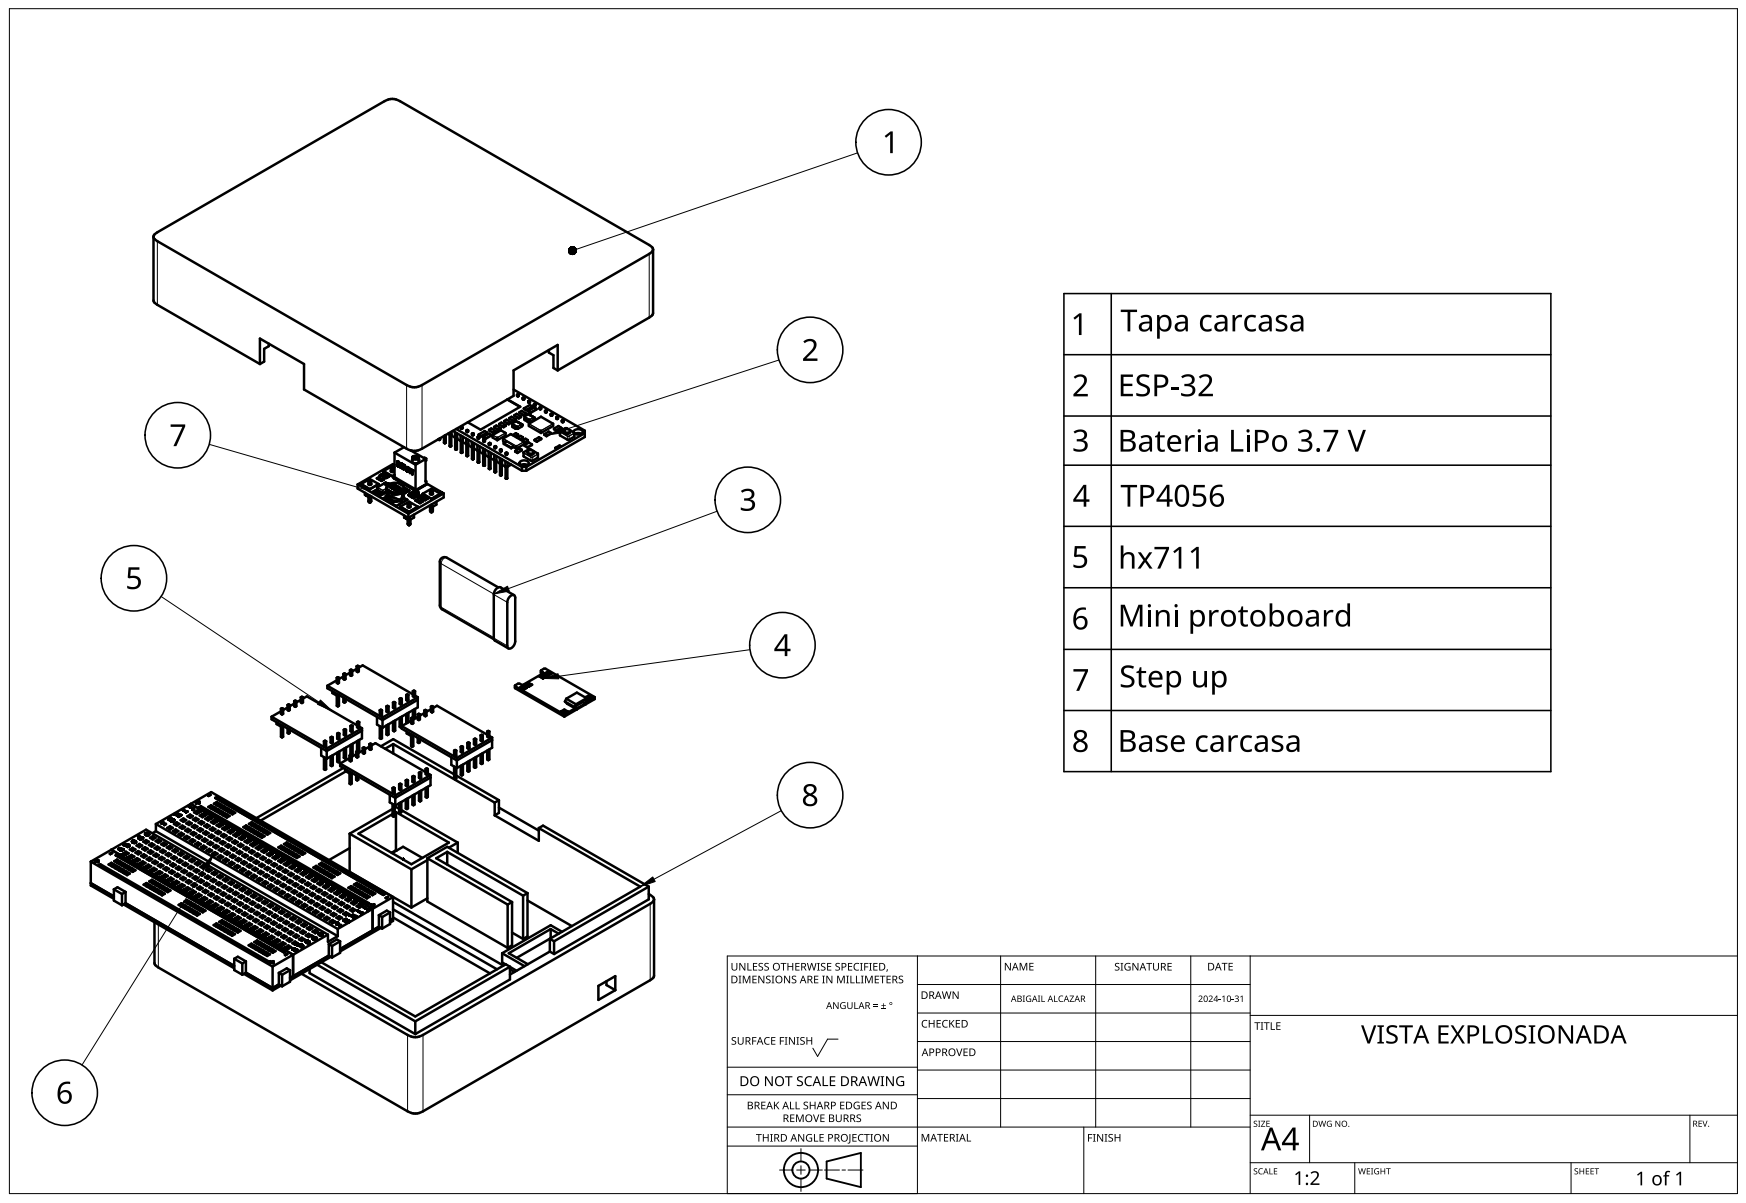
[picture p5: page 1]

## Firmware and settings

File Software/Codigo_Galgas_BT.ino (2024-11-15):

#include <HX711.h>
#include "BluetoothSerial.h"

// Definir los pines de cada HX711
const int LOADCELL_DOUT_1 = 15; // Pin DOUT para el HX711 1
const int LOADCELL_SCK_1 = 5;   // Pin SCK para el HX711 1
const int LOADCELL_DOUT_2 = 2;  // Pin DOUT para el HX711 2
const int LOADCELL_SCK_2 = 18;  // Pin SCK para el HX711 2
const int LOADCELL_DOUT_3 = 4;  // Pin DOUT para el HX711 3
const int LOADCELL_SCK_3 = 19;  // Pin SCK para el HX711 3
const int LOADCELL_DOUT_4 = 16; // Pin DOUT para el HX711 4
const int LOADCELL_SCK_4 = 21;  // Pin SCK para el HX711 4

// Crear instancias para cada HX711
HX711 scale1;
HX711 scale2;
HX711 scale3;
HX711 scale4;

// Configuración de Bluetooth
String device_name = "Medidor-Presion-PrototipoESP32-BT";
BluetoothSerial SerialBT;

void setup() {
  Serial.begin(115200);

  // Iniciar las balanzas (HX711)
  scale1.begin(LOADCELL_DOUT_1, LOADCELL_SCK_1);
  scale2.begin(LOADCELL_DOUT_2, LOADCELL_SCK_2);
  scale3.begin(LOADCELL_DOUT_3, LOADCELL_SCK_3);
  scale4.begin(LOADCELL_DOUT_4, LOADCELL_SCK_4);
  Serial.println("Iniciando lectura de los HX711...");

  // Iniciar Bluetooth
  SerialBT.begin(device_name);
  Serial.printf("El dispositivo de nombre \"%s\" esta disponible.\nAhora puedes emparejarlo con Bluetooth!\n", device_name.c_str());
  SerialBT.deleteAllBondedDevices(); // Borra todos los dispositivos emparejados
}


void loop() {
  // Lecturas de los HX711
  if (scale1.is_ready()) {
    long reading1 = scale1.read();
    Serial.print("Lectura HX711 1: ");
    Serial.println(reading1);
    SerialBT.print("Lectura HX711 1: ");
    SerialBT.println(reading1);
  } else {
    Serial.println("Esperando HX711 1...");
  }

  if (scale2.is_ready()) {
    long reading2 = scale2.read();
    Serial.print("Lectura HX711 2: ");
    Serial.println(reading2);
    SerialBT.print("Lectura HX711 2: ");
    SerialBT.println(reading2);
  } else {
    Serial.println("Esperando HX711 2...");
  }

  if (scale3.is_ready()) {
    long reading3 = scale3.read();
    Serial.print("Lectura HX711 3: ");
    Serial.println(reading3);
    SerialBT.print("Lectura HX711 3: ");
    SerialBT.println(reading3);
  } else {
    Serial.println("Esperando HX711 3...");
  }

  if (scale4.is_ready()) {
    long reading4 = scale4.read();
    Serial.print("Lectura HX711 4: ");
    Serial.println(reading4);
    SerialBT.print("Lectura HX711 4: ");
    SerialBT.println(reading4);
  } else {
    Serial.println("Esperando HX711 4...");
  }

  // Comunicación bidireccional con Bluetooth
  if (Serial.available()) {
    SerialBT.write(Serial.read());
  }
  if (SerialBT.available()) {
    Serial.write(SerialBT.read());
  }

  delay(1000); // Espera de 1 segundo entre lecturas
}

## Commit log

2024-08-27 carpeta de entregables
2024-09-04 Nueva Carpeta con el caso
